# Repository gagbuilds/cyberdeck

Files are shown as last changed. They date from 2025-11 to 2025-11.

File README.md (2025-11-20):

# cyberdeck

A portable cyberdeck designed around accessories and working on the move.

***Why?***
There are many game consoles out there, like the nintendo switch, and the steamdeck. I find the integrated controllers with the screen to be awesome for portability, while lacking in quality compared to standalone controllers. So? I created a high quality controller, connected comfortably to the screen. The cyberdeck in particular, has a interesting feature I wanted to tackle for true portability. **The keyboard.** Unlike a traditional laptop, which requires to be unfolded and set on a surface, the portable cyberdeck can type on the move. Using hand tracking algorithms, it can type different keystrokes, depending on the set distance ones fingers move. The picatinny rails attach to slings further complimenting this approach.

## Key features
* **Controllers**
  * 4x Distance Sensors (Hand Tracking): Predictive Steganography & normal typing switch
  * Joystick & Scroll Wheel: Moving cursor, scrolling, zooming & typing
  * Analog Trigger + Buttons: Clicks & keybinds
* **Shock Cage**
  * Springs can withstand <0.75m drop, rubber grommets for additional acceleration damping.
* **Travel Mode**
  * Foldable controllers on both sides for compact travel
  * When deployed: Space for a cooling fan, lowered controllers used as a stand, & space between controller & main body to strap to arm for carrying
* **Picatinny Rails**:
  * Used to attach custom gadgets to the device. Ex: Gun sling, or 3d printed mount
* **Physical Toggle Switches**
  * Toggle power & battery, software modes

## How to Assemble

There are three parts to this.
* Ordering BOM
* Fabricating PCB
* 3d Printing Parts (Check CAD folder)
* Putting it together

I figure most can get the first three done, but I'll go into detail for putting it together.

### Soldering the controller board

You can *in theory* solder this by hand, but I'd recommend using a **hot plate** to put on the **distance sensors** since they have ***tiny*** pads.
* Apply solder paste
* Heat the board on the pad

Next you'll put on the **joystick** and the other **non-SMD components**, including the buttons. A tip for the buttons is to only **solder diagonal pins** (look at the adafruit page video for more details).

Lastly, the Raspberry Pi Pico will go on. You'll want to **solder** on the **female pins** before putting on the board, so if it ever gets fried, or you want to take it off for some reason, it's super easy. Once the female pins have been soldered on the board, you just have to solder the male pins on the Raspberry Pi Pico, and attach it all together!

### Final Steps

From here on out, it's just two things.

1. Flashing firmware
2. Connecting to the main board

Connecting to the main board consists of the two power cables (+5v AND GND), and the **UART half-duplex** cable. Reference your Raspberry Pi pinout for more details on which pins to connect. It may vary per model, and you may already have some of the pins connected to other components. (This cyberdeck can act as a server when not in use)

To flash the firmware, open up the Arduino IDE, and copy and paste the code from the repository to both picos.

## Showcase

*Controller PCB*
cont pcb

*Controller Schematic*
cont sch

*Cyberdeck Shock Cage* 
shock cage

*Cyberdeck Overview*
overview

# Project Bill of Materials

**Total Cost: $390.36**

## Main Body - $277.55

### Computing - $20.00

| Component | Quantity | Price  | Link | Notes |
| --- | --- | --- | --- | --- |
| Raspberry Pi 5 8GB | 1 | - | - | Already purchased |
| Top+Bottom Passive Heatsink | 1 | $7.00  | [Digikey](https://www.digikey.com/en/products/detail/edatec/ED-PI5CASE-OS/21769633) | |
| 5V 5A Power Supply | 1 | $13.00 | [Amazon](https://www.amazon.com/GeeekPi-Power-Supply-Raspberry-Adapter/dp/B0CQ2DL2RW) | |

### Hotswap Connectors & Controller Folding System - $13.42

| Component | Quantity | Price | Link | Notes |
| --- | --- | ----- | --- | ----- |
| 200mm Metal Rods | 2 | $5.04 | [AliExpress](https://www.aliexpress.us/item/3256806550938490.html) | |
| Spring Loaded Contacts | 6 | $3.96 | [Digikey](https://www.digikey.com/en/products/detail/mill-max-manufacturing-corp/0906-2-15-20-75-14-11-0/1147050) | |
| Small Magnets | 14 | $4.42 | [Digikey](https://www.digikey.com/en/products/detail/radial-magnets-inc/8193/555328) | |

### Shock Cage - $18.98

| Component | Quantity | Price | Link | Notes |
| --- | --- | ----- | --- | ----- |
| Springs | 16 | $8.99 | [Amazon](https://www.amazon.com/Dianrui-Compression-Assortment-Mechanical-K-P-051-300/dp/B0BVTDP29W/143-1548753-7471335) | |
| Grommets  | 16 | $9.99 | [Amazon](https://www.amazon.com/200PCS-Grommet-Electrical-Firewall-Assortment/dp/B08CD9KGHN) | |

### Mesh Arm Mount - $5.00

| Component | Quantity | Price | Link | Notes |
| --- | --- | ----- | --- | --- |
| Mesh | 1 | $5.00 | [Walmart](https://www.walmart.com/ip/Polyester-Knit-Diamond-Mesh-Fabric-Black-Sheer-Polyester-63-By-The-Yard/2555999935) | Local catalogue |

### Other Components - $220.15

| Component | Quantity | Price  | Link | Notes |
| --- | --- | --- | --- | --- |
| Toggle Switch | 5 | - | - | Already own |
| Display | 1 | $146.50 |[ ebay ](https://www.ebay.com/itm/376644181301) | |
| Heat Set Inserts | 50 | $7.39  | [Digikey](https://www.digikey.com/en/products/detail/tri-star-industries-inc/M20X157C/13535373) | |
| M2 Screws | 1 set | $12.99 | [Amazon](https://www.amazon.com/DYWISHKEY-Pieces-Stainless-Phillips-Screws/dp/B07W5J4WC9) | |
| PETG Plastic Spool  | 1 | $18.00 | - | For 3D printing, local printer reimbursement |
| Battery | 1 | $26.97 | [Amazon](https://www.amazon.com/INIU-Portable-20000mAh-High-speed-Flashlight/dp/B07YPY31FL) | |
| Voltage Regulator | 1 | $5.30  | [Digikey](https://www.digikey.com/en/products/detail/dfrobot/DFR1015/18069278) | |
| USB-C PD Negotiator | 1 | $3.00  | [AliExpress](https://www.aliexpress.us/item/3256806276110723.html) | |

## Controller - $112.81

### Main Components - $100.36

| Component | Quantity | Price  | Link | Notes |
| --- | --- | --- | --- | ----- |
| JH16 Joystick | 2 | $11.01 | [AliExpress](https://www.aliexpress.com/i/3256808274885275.html) | |
| Hall Effect Sensor | 2 | $2.30  | [Digikey](https://www.digikey.com/en/products/detail/allegro-microsystems/A1315LLHLX-5-T/8032467) | |
| Soft Tactile Switch | 4 | $1.95  | [Adafruit](https://www.adafruit.com/product/3101) | |
| Rotary Encoder | 2 | $3.22  | [Digikey](https://www.digikey.com/en/products/detail/tt-electronics-bi/EN12-VN20AF20/2408775?gQT=2) | |
| Mini Motor Disc | 2 | $8.16  | [Adafruit](https://www.adafruit.com/product/1201) | |
| Raspberry Pi Pico | 2 | $19.16 | [Adafruit](https://www.adafruit.com/product/5544) | |
| PCB | 2 | $18.89 | JLCPCB | |
| I2C Distance Sensor (VL6180X) | 10 | $32.05 | [Digikey](https://www.digikey.com/en/products/detail/stmicroelectronics/VL53L4CDV0DH-1/16123783) | |
| Op-Amp | 4 | $1.52  | [Digikey](https://www.digikey.com.br/en/products/detail/texas-instruments/LMV358IDR/381251) | |
| Linear Regulator | 2 | $1.36  | [Digikey](https://www.digikey.com/en/products/detail/umw/AMS1117-3-3/17635254) | |
| 180kΩ SM Resistor | 4 | $0.40  | [Digikey](https://www.digikey.com/en/products/detail/yageo/RC0603JR-07180KL/726723) | |
| 330kΩ SM Resistor | 4 | $0.40  | [Digikey](https://www.digikey.com/en/products/detail/yageo/RC0603JR-07330KL/726770) | |

### Knuckle Straps - $12.45

| Component | Quantity | Price | Link | Notes |
| --- | --- | ----- | --- | ----- |
| Cloth | 2 | $3.97 | [Walmart](https://www.walmart.com/ip/Dritz-Hanked-Non-Roll-Woven-Elastic-Black-Sewing-Fasteners/5226743025) | |
| Spring Loaded Cord Fastener | 2 | $3.00 | [Amazon](https://www.amazon.com/Cord-Upgraded-Fastener-Shoelaces-Drawstrings/dp/B08JTZPQRY) | |
| Paracord | 1 | $5.48 | [Walmart](https://www.walmart.com/ip/Ozark-Trail-50-Foot-1100lbs-Paracord-Rope-100-Polyester-Black-Model-2112/311952813) | |

---

## Cost Summary

| Section | Cost |
| --- | --- |
| Main Body  | $277.55 |
| Controller | $112.81 |
| **Total**  | **$390.36** |

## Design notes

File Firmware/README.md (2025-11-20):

# Controller Reference Guide

Since I don't have the actual board and components, it's impossible to test the code I will create. I've linked together a network of relevant tutorials I will be using to problem shoot.

The firmware will be written in C++ using the Arduino IDE & many libraries.

## Parts

- How to create UART connections in arduino
- How to read ADC / hall effect sensors
- Distance sensor firmware & I2C protocol
- How to read buttons (Connected to GND pin)

### UART Connections in Arduino

This shouldn't be too hard to set up. I'll be using a serial connection with a certain baud rate that'll allow one way communication from the pico to the main board. The reference youtube tutorial: https://www.youtube.com/watch?v=P0O9sVRe15I

### Reading ADC values (Analog to Digital)

From what I've seen online it's as simple as this small bit of code

```
void loop() {
  int hallValue = analogRead(hallSensorPin);
}
```

### Distance sensor firmware & I2C protocol

I'll need to import vl53l4cd_api.h, and I'll be referencing this library. Since I have multiple sensors, I'll be looping individual through them and toggling on and off the xshut pins while communicating over I2C. https://github.com/stm32duino/VL53L4CD

### Reading Buttons

Since my buttons are connected to GND and a pin, I need to set the GPIO pins to PULL UP mode, and then detect the current state with the digital read function

```
pinMode(buttonPin, INPUT_PULLUP);
//and also
int buttonState = digitalRead(buttonPin);
```

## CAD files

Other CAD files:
CAD/Full_Cyberdeck.step

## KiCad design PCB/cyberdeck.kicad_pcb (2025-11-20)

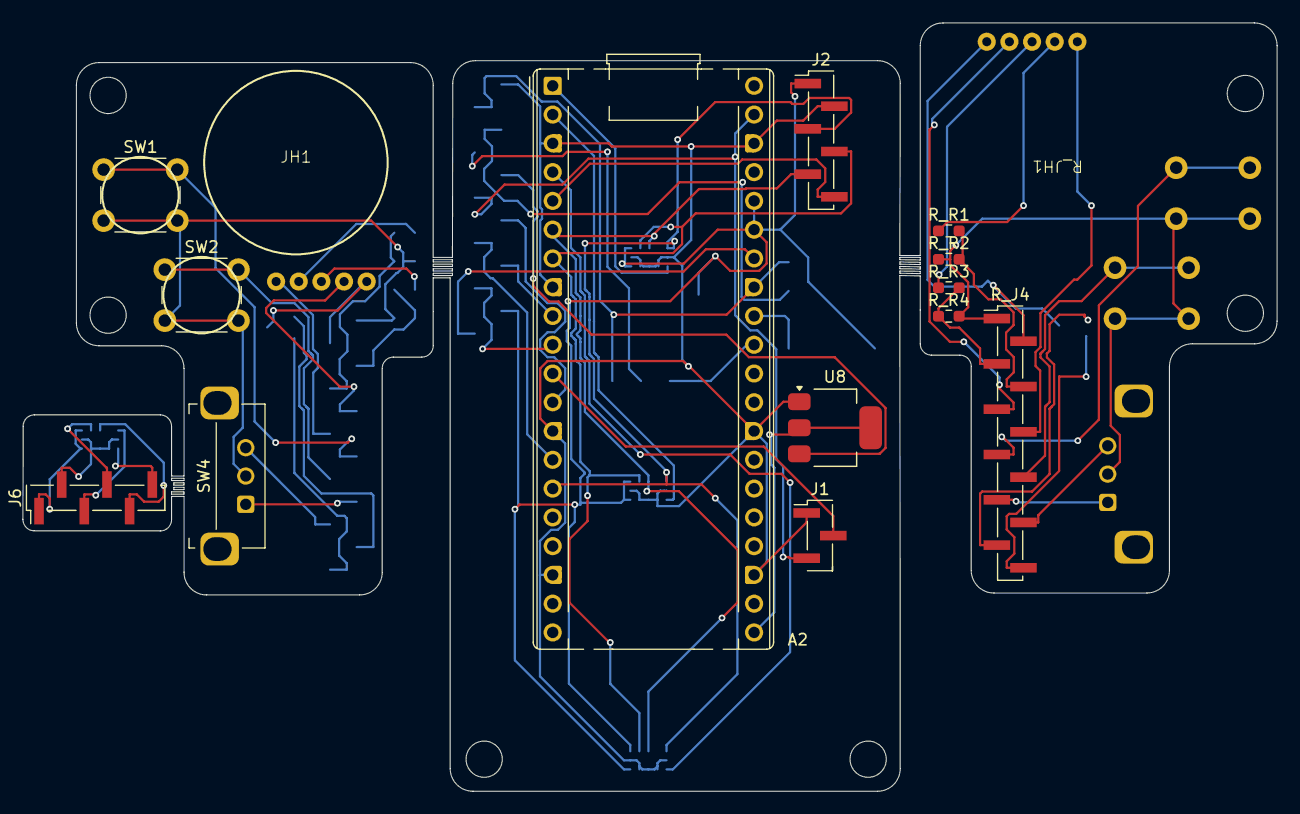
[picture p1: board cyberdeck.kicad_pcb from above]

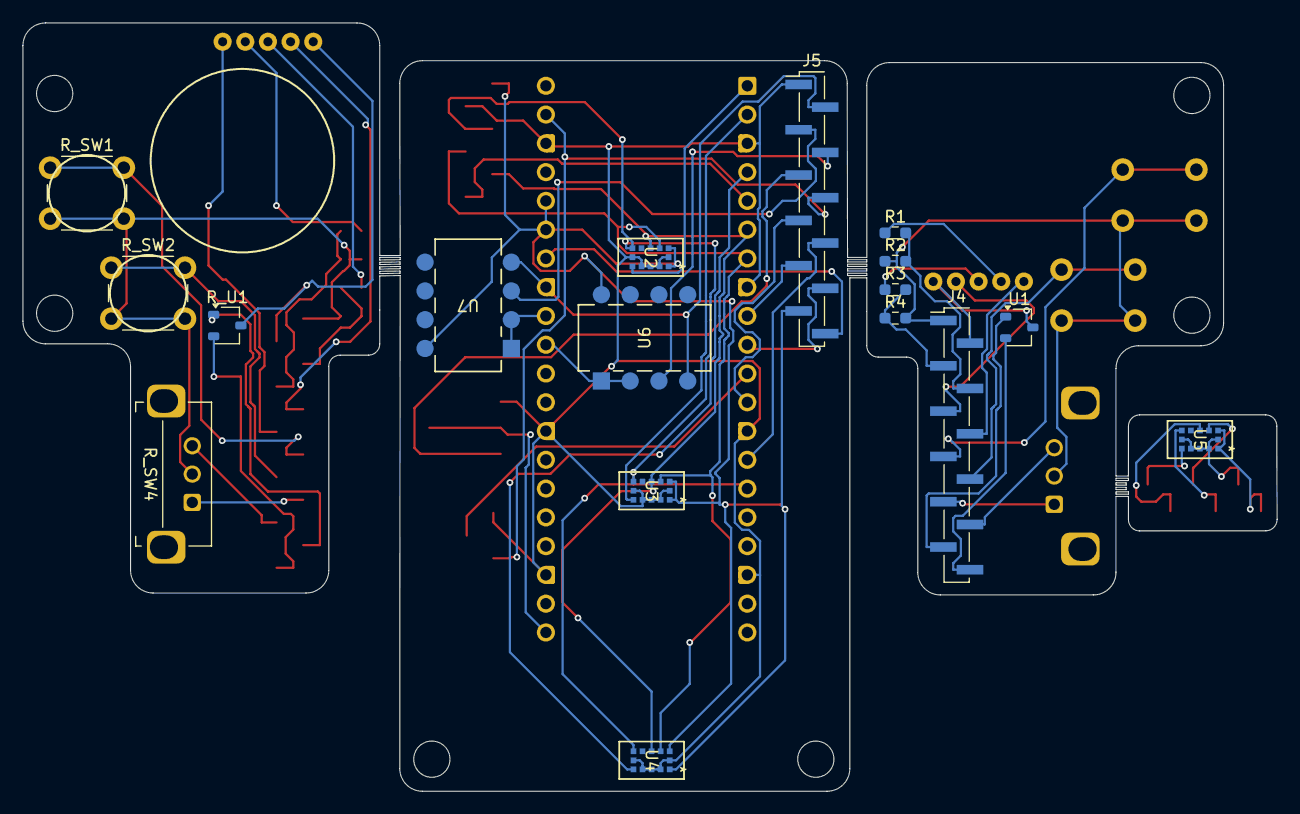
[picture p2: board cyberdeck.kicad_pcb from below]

Board: 2 copper layers, 110.7 x 67.8 mm, 38 parts (19 on the bottom side), 43 nets.

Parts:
A2: RaspberryPi_Pico_W; RaspberryPi_Pico_Common_THT
J1: Conn_01x03; PinHeader_1x03_P2.00mm_Vertical_SMD_Pin1Left
J2, J6: Conn_01x06; PinHeader_1x06_P2.00mm_Vertical_SMD_Pin1Left
J4, J5: Conn_01x12; PinHeader_1x12_P2.00mm_Vertical_SMD_Pin1Left
JH1: JH16
M1, M2, M3, M4, M5, M6: MountingHole_3.2mm_M3
R1, R2, R3, R4: R; R_0603_1608Metric_Pad0.98x0.95mm_HandSolder
R_J4: Conn_01x12; PinHeader_1x12_P2.00mm_Vertical_SMD_Pin1Left
R_JH1: JH16
R_R1, R_R2, R_R3, R_R4: R; R_0603_1608Metric_Pad0.98x0.95mm_HandSolder
R_SW1, R_SW2: SW_Push; SW_PUSH_6mm_H8mm
R_SW4: RotaryEncoder; RotaryEncoder_Bourns_Horizontal_PEC12R-2x17F-Nxxxx
R_U1: A1308xLHxx-1; SOT-23W
SW1, SW2: SW_Push; SW_PUSH_6mm_H8mm
SW4: RotaryEncoder; RotaryEncoder_Bourns_Horizontal_PEC12R-2x17F-Nxxxx
U1: A1308xLHxx-1; SOT-23W
U2, U3, U4, U5: VL53L4CDV0DH/1; LGA12_STM
U6, U7: LMV358; DIP8_300
U8: AMS1117-3.3; SOT-223-3_TabPin2

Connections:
+3.3V: A2.35 (ADC_VREF), A2.36 (3V3), J2.1, J5.11, U2.1 (AVDDVCSEL), U2.11 (AVDD), U3.1 (AVDDVCSEL), U3.11 (AVDD), U4.1 (AVDDVCSEL), U4.11 (AVDD), U6.8 (V+), U7.8 (V+)
A: A2.9 (GPIO6), J5.9
AGND: A2.33 (AGND), J5.2, U6.4 (V-), U7.4 (V-)
B: A2.10 (GPIO7), J5.10
D1_XSHUT: A2.1 (GPIO0), U2.5 (XSHUT)
D2_XSHUT: A2.2 (GPIO1), U3.5 (XSHUT)
D3_XSHUT: A2.4 (GPIO2), U4.5 (XSHUT)
D4_XSHUT: A2.5 (GPIO3), J2.6
DATA: A2.11 (GPIO8), J1.2
External 5v: A2.39 (VSYS), J1.3, J5.6
GND: A2.3 (GND), A2.8 (GND), A2.13 (GND), A2.18 (GND), A2.23 (GND), A2.28 (GND), A2.38 (GND), J1.1, J2.2, J5.1, U2.2 (AVSSVCSEL), U2.3 (GND), U2.4 (GN2), U2.6 (GND3), U2.12 (GND4), U3.2 (AVSSVCSEL), U3.3 (GND), U3.4 (GN2), U3.6 (GND3), U3.12 (GND4), U4.2 (AVSSVCSEL), U4.3 (GND), U4.4 (GN2), U4.6 (GND3), U4.12 (GND4), U8.1 (GND)
JH_SW: J5.5, U8.3 (VI)
J_3.3v: J4.11, R_J4.11, R_U1.1 (V_{CC}), U1.1 (V_{CC})
J_A: J4.9, R_J4.9, R_SW4.A, SW4.A
J_AGND: J4.2, JH1.5 (GND), R_J4.2, R_JH1.5 (GND), R_U1.3 (GND), U1.3 (GND)
J_B: J4.10, R_J4.10, R_SW4.B, SW4.B
J_External 5v: J4.6, JH1.1 (VCC), R_J4.6, R_JH1.1 (VCC)
J_GND: J4.1, R2.1, R4.2, R_J4.1, R_R2.1, R_R4.2, R_SW1.2, R_SW2.2, R_SW4.C, SW1.2, SW2.2, SW4.C
J_JH_SW: J4.5, JH1.4 (Switch), R_J4.5, R_JH1.4 (Switch)
J_SW1: J4.7, R_J4.7, R_SW1.1, SW1.1
J_SW2: J4.8, R_J4.8, R_SW2.1, SW2.1
J_Trigger_ADC: J4.12, R_J4.12, R_U1.2 (V_{OUT}), U1.2 (V_{OUT})
J_X_ADC: J4.4, R1.2, R2.2, R_J4.4, R_R1.2, R_R2.2
J_Y_ADC: J4.3, R3.2, R4.1, R_J4.3, R_R3.2, R_R4.1
unnamed: A2.15 (GPIO11), J2.3, U2.7 (GPIO1), U3.7 (GPIO1), U4.7 (GPIO1)
unnamed: A2.21 (GPIO16), U8.2 (VO)
unnamed: J5.3, U7.3 (+)
unnamed: J5.4, U6.3 (+)
unnamed: JH1.2 (X), R1.1, R_JH1.2 (X), R_R1.1
unnamed: JH1.3 (Y), R3.1, R_JH1.3 (Y), R_R3.1
SCL: A2.7 (GPIO5), J2.4, U2.10 (SCL), U3.10 (SCL), U4.10 (SCL)
SDA: A2.6 (GPIO4), J2.5, U2.9 (SDA), U3.9 (SDA), U4.9 (SDA)
SW1: A2.12 (GPIO9), J5.7
SW2: A2.14 (GPIO10), J5.8
T_3.3v: J6.1, U5.1 (AVDDVCSEL), U5.11 (AVDD)
T_D4_XSHUT: J6.6, U5.5 (XSHUT)
T_GND: J6.2, U5.2 (AVSSVCSEL), U5.3 (GND), U5.4 (GN2), U5.6 (GND3), U5.12 (GND4)
T_GPIO1: J6.3, U5.7 (GPIO1)
T_SCL: J6.4, U5.10 (SCL)
T_SDA: J6.5, U5.9 (SDA)
Trigger_ADC: A2.34 (GPIO28_ADC2), J5.12
X_ADC: A2.31 (GPIO26_ADC0), U6.1, U6.2 (-)
Y_ADC: A2.32 (GPIO27_ADC1), U7.1, U7.2 (-)

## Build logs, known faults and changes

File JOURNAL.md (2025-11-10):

<!--
  ===================    !!READ THIS NOTICE!!   ====================
  DO NOT edit this file manually. Your changes WILL BE OVERWRITTEN!
  This journal is auto generated and updated by Hack Club Blueprint.
  To edit this file, please edit your journal entries on Blueprint.
  ==================================================================
-->

## 11/1/2025 - rough schematics  

Decided to finally start working on the project after procrastinating for days, I noticed that there is only one month of blueprint left, hence i had to finish my deck quickly, so i started of by sketching my whole idea :)



## 11/2/2025 9:19 AM - Display troubles  

Effective displays land in two areas:

Raspberry Pi specific:
Low resolution (1040x600 or 1280x720) touch, sometimes still expensive
(sometimes) Non-touch laptop displays
Higher resolution no touch, more power draw
In this case, the choice I went with a 10.5 inch touchscreen display at the cost of ~$112 on ebay. It's 1920x1280, which is perfect for programming, given the extra vertical height.
https://www.ebay.com/itm/376644181301


I've been brainstorming the attachment mechanism between the main body and the controllers. Here's the plan. I'll have a ball bearing rectangle piece rotate to lock into the controller, which will have magnets. This piece will also have 3 wires routed on it. GND, 3.3v line, and a data line. These will be connected using spring loaded contacts to the wires. Since I'll have extra magnets, there's a good chance the end of the rotatable travel mode will have magnets to lock it into, as vice versa in the opposite mode. This day has been mostly just double checking all of the materials, and doing more indepth price checks  

## 11/2/2025 9:23 AM -  Ideas! Stenography, Shock Cages, and a beginning to the mod  

Coming back from a hardware hackathon, I have a couple of extra ideas.

Stenography typing at it's most basic level is typing chords. The left hand deals with beginning consonants, the thumbs vowels, and right hand ending consonants. To make it work, I would use the joysticks for the different thumb keys. This could be surprisingly effective, since the nature of capacitive keys allow predictive text. With it, I'm also considering adding a fifth capacitive sensor above the trigger module to allow for more streamlined typing

Inspired from this post https://community.element14.com/products/raspberry-pi/f/forum/8653/case-material-to-protect-raspberry-pi-3b-and-zero-in-hostile-environment

-Shock cages are not very common, but the nature of the cyberdeck revolves around portability. I'm designing it to survive drops that hit the handles, screen side, or back side of the deck. There are two parts to the shock absorption

-Springs: Designed for small drops <0.75m, I can calculate the stiffness required by doing some physics. The potential energy of the shock cage is calculated using weight and height, then I equal that to the elastic potential energy of the spring x4.

-Rubber Grommets: If a fall is greater than 0.75m, then the grommets will somewhat dampen the impact, if much less effectively.

drawings

## 11/2/2025 9:26 AM - Familiarization with Onshape  

I've been modeling the case to work with the eyoyo 10.5 inch touchscreen display. The specs I've found online to help me are: 232.918mm x 165.1mm x 7.874mm. I'll need to mount it using a VESA mount blueprint from the back. Since I've never worked in onshape, I've been going through the tutorial to learn the basics.

onshape

## 11/3/2025 1:08 PM - Deck Main Body: Heatset inserts & sizing  

I've created the walls with another sketch, and have done a bit of tweaking to fit the M2 sized holes for the heatset inserts. The roadtrip has been causing quite a bit of internet trouble, meaning the rate at which I can work is heavily affected. I've also started on the footprint for the picatinny rails.
main_body

## 11/3/2025 1:11 PM - Picatinny Rails, bottom plate & port blocks  

I've finished creating the picatinny rails. This uses specific dimensioning from a sketch and I've created it with appropriate constraints if ever needed to be further modified. The rails are on a feature pattern which made it possible to easily modify the length for both sides, with a separated part allowing me to mirror it. Each of the parts I'm adding has been measured (RPi 5, toggle switches) to the correct length. I'll have 5 toggle switches on the right side, and the RPi ports on the left side. A big challenge was figuring out I was going to create a hinge for the rotation mechanism. I spent around two hours researching how to do this. My original idea was to use a bicycle/skateboard bearing, but it wasn't the right fit. Rather, just sliding a metal rod through rings slotted together kept everything secure. When I want to move it, I'll slide the rod forward which unlocks the hinges to move.




## 11/3/2025 1:14 PM - Mesh Arm Mount  

I spent a lot of time on another idea I had. Since the cyberdeck's main theme is portability, I want to give ample opportunity to different methods of traveling. To make traveling with it arm mounted, I decided to layer a mesh on the bottom through the center. This allows the arm to sink into the deck, which has space since the shock cage springs will not be compressed. I've researched some material options and so far the best option is ballistic nylon mesh. I'm going to layer it between two pieces of plastic and secure it with a hex nut. In addition I've been tweaking the hinge design, and I've expanded it significantly to support the weight, while also adding a circular touch to make it look nicer.
mesh arm mount

## 11/3/2025 1:26 PM - Finished Mesh Arm Mount + Progress on pivot arms  

I've been struggling a lot with adjustments of all sorts of things. This has been a learning experience on how to properly create constraints to rely only on base structures in the proper format. I've completed the bottom parts to secure the mesh layer, meaning all I need to focus on from now on are the arm mechanisms, and finally the controller.



## 11/10/2025 6:33 PM - Pivot Connection  

I created the connection piece for the pivot point from the main body base. It was difficult to create the necessary curves as I kept getting errors. Eventually I created two Fillets separate for the top and bottom, and while it isn't flush, it worked. I also created the extra sandwich layer



## 11/10/2025 6:34 PM - First Main Body Print  

I just got one of my first prints back. This will help me immensely with finishing up the body as I'll have something physical to work with and think through the design better. I've noticed that the ports for the toggle switch are a bit too big, and so I've trimmed those down. Other than that, probably just in the next version make sure to include spring mounts.

first print

## 11/10/2025 6:53 PM - Redesigned Controller & Pivot Controller Mount Progress  

I redesigned the controller again. It wasn't feeling quite right, which I found more impactful when the new design emerged with a much more usable joystick & button area at the top. Of course, the struggles don't end there. I had to learn the technique for creating a multi-directional plane on onshape, rather than a single axis one. After splitting it, the next challenge was hollowing them out. The bottom part of the joystick was easy, and it worked first try. However, when I attempted to hollow out the top part of the controller, I kept getting errors. Funnily enough, the solution is nonsensicle. Selecting a side plane next to where the error is did nothing extra, but still removed the error.

With that out of the way, my next step was creating a connection between the two pieces. My original plan was to have two screws on the bottom. This didn't work out however, since the holes were too deep and the design becoming too complicated. I instead settled on sideways screws by expanding up and using a chamfer to tidy it up.

At this point I hit a bit of a mental roadblock. I didn't know where to begin with creating the mount piece that allows the pivot to slot into the controller. Eventually, I just had to start trying sketches, which helped remove the mental block. This leads me to my most current progress for today! I've shown it below.

cont redesign

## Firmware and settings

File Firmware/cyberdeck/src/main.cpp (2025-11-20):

#include <Arduino.h>
#include <vl53l4cd_class.h>
#include <Wire.h>

#define DEV_I2C Wire

#define HALL_EFFECT_PIN 1
#define XSHUT_PIN 2
#define DISTANCE_PIN_AMT 4
#define interruptPin 5

// define methods at the top
void distanceRead();
void measure();

volatile int interruptCount = 0;

VL53L4CD sensor_vl53l4cd_sat(&DEV_I2C, XSHUT_PIN);

void setup()
{
  // The controller has one DATA wire for one-way SERIAL communication.
  // Recommended RPi Pico Baud Rate is: 115200 bits/s
  Serial.begin(115200);

  // Interrupt Pin (GPIO1) used for signaling ready data
  pinMode(interruptPin, INPUT_PULLUP);
  attachInterrupt(interruptPin, measure, FALLING);

  // Initialize XSHUT pins
  for (int i = 0; i < DISTANCE_PIN_AMT; i++)
  {
    pinMode(XSHUT_PIN + i, OUTPUT);
    // Turn off sensor
    digitalWrite(XSHUT_PIN + i, LOW);
  }
}

// This program is tracking multiple controller inputs. Here are the sections of what it is tracking
/*
  - 1x Hall Effect Sensor: Analog Trigger
  - 4x I2C Distance Sensor: Hand Tracking
  - 2x (X, Y) Hall Effect Sensor: Analog Joystick
  - 1x Switch to 3.3V: Joystick Button
  - 2x Switch to GND: Toolhead Buttons
*/

void loop()
{
  // Hall Effect Sensor
  int analogTrigger = analogRead(HALL_EFFECT_PIN);
  // I2C Distance Sensor
  distanceRead();

  // 10 reads per second
  delay(100);
}

void distanceRead()
{
  // Initialize I2C Bus
  DEV_I2C.begin();

  // Configure VL53L4CD satellite component.
  sensor_vl53l4cd_sat.begin();

  // Initialize VL53L4CD satellite component.
  sensor_vl53l4cd_sat.InitSensor();

  // Program the highest possible TimingBudget, without enabling the
  // low power mode. This should give the best accuracy
  sensor_vl53l4cd_sat.VL53L4CD_SetRangeTiming(200, 0);

  // Start Measurements
  sensor_vl53l4cd_sat.VL53L4CD_StartRanging();
}

void measure()
{
  interruptCount = 1;
}
